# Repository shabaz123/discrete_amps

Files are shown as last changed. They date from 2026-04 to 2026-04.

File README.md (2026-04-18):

# Discrete Amps

This repository contains  discrete audio amplifier designs intended primarily for speech applications (speech bandwidth, not music).  

Each design includes:
- KiCad 10 Schematic and PCB files
- KiCad 10 SPICE Simulation Workbook
- Gerber files for fabrication  
- PDF schematic export and PCB screenshots for easy viewing without KiCad  

---

## Preamp K1

Designed by M. Kellett, this preamplifier is optimised for speech signals in HF receivers.

- **Gain:** ~28 dB  
- **Bandwidth (-3 dB):** ~150 Hz to 10 kHz (approximate)  
- **Use case:** Moderate gain front-end with relatively wide speech bandwidth  

### Schematic
K1 Schematic

### PCB Top
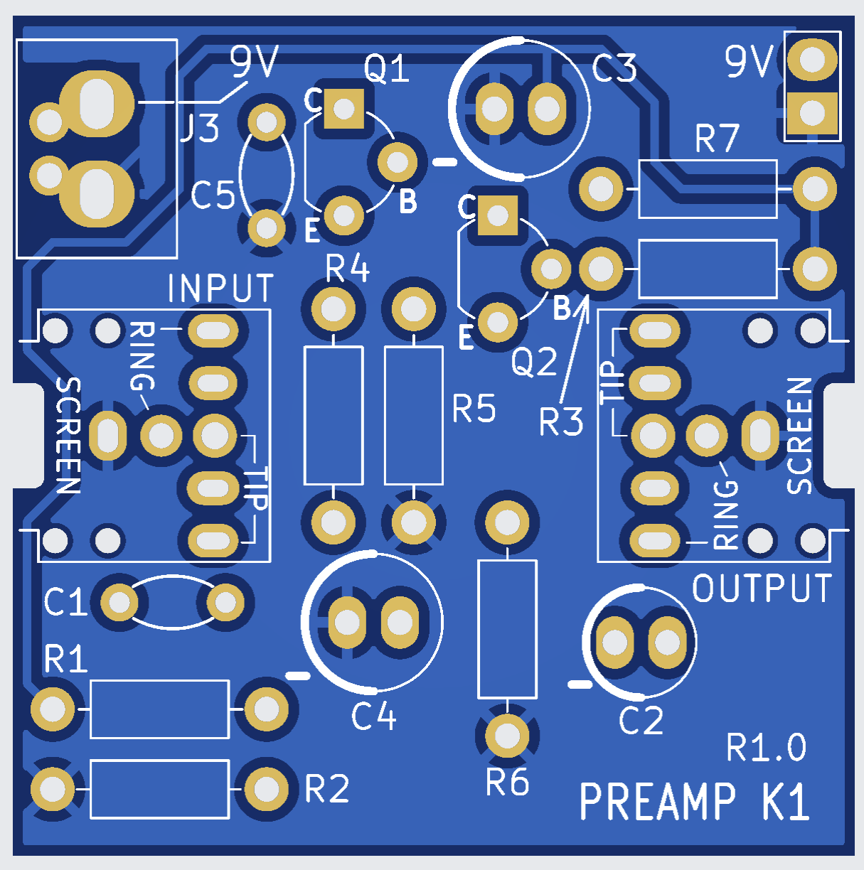
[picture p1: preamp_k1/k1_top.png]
K1 Top


### PCB Underside
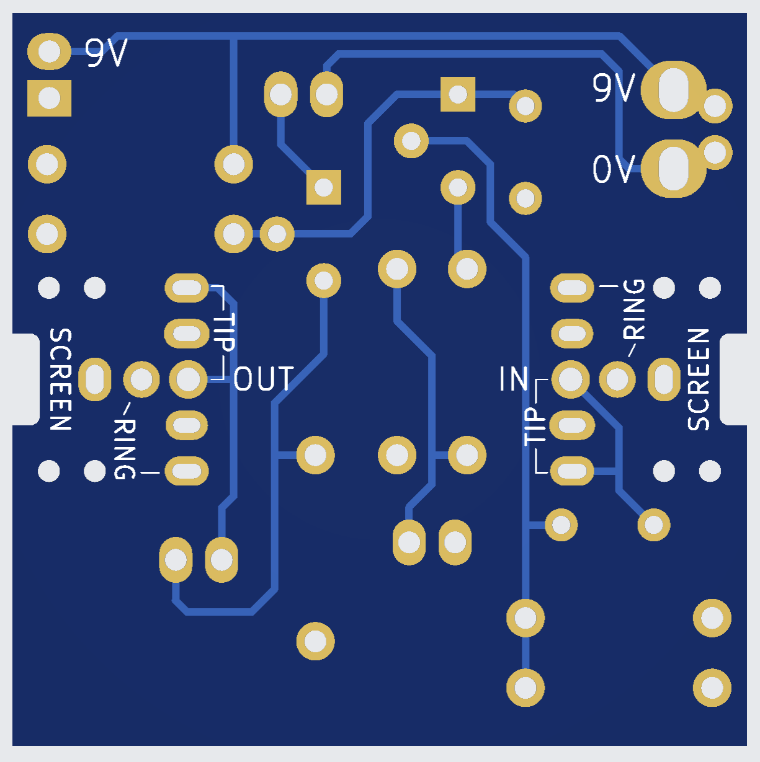
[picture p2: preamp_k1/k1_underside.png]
K1 Underside


### PCB Render
K1 Render

---

## Preamp K2

Also designed by M. Kellett, this version provides higher gain and a slightly narrower bandwidth, making it suitable where additional amplification is required.

- **Gain:** ~45 dB  
- **Bandwidth (-3 dB):** ~100 Hz to 7 kHz (approximate)  
- **Use case:** Higher gain stage for weak signal amplification  

### Schematic
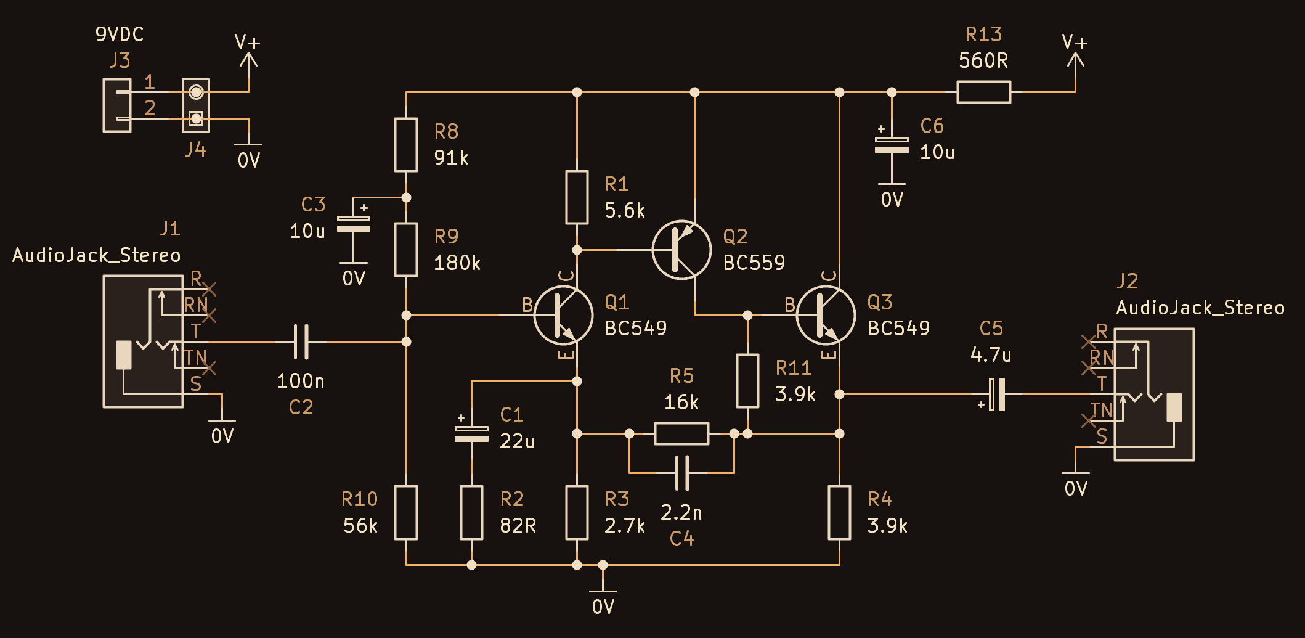
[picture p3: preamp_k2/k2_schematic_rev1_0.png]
K2 Schematic


### PCB Top
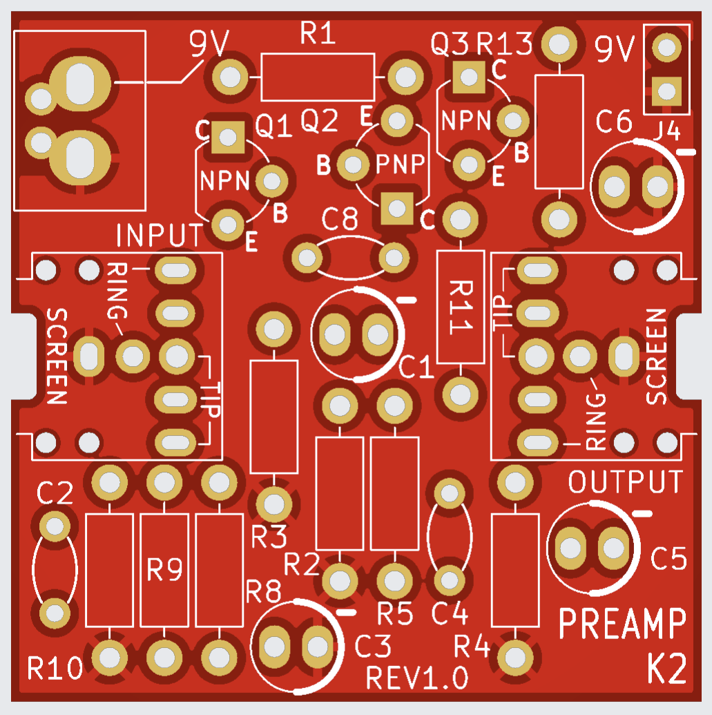
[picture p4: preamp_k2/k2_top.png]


### PCB Underside
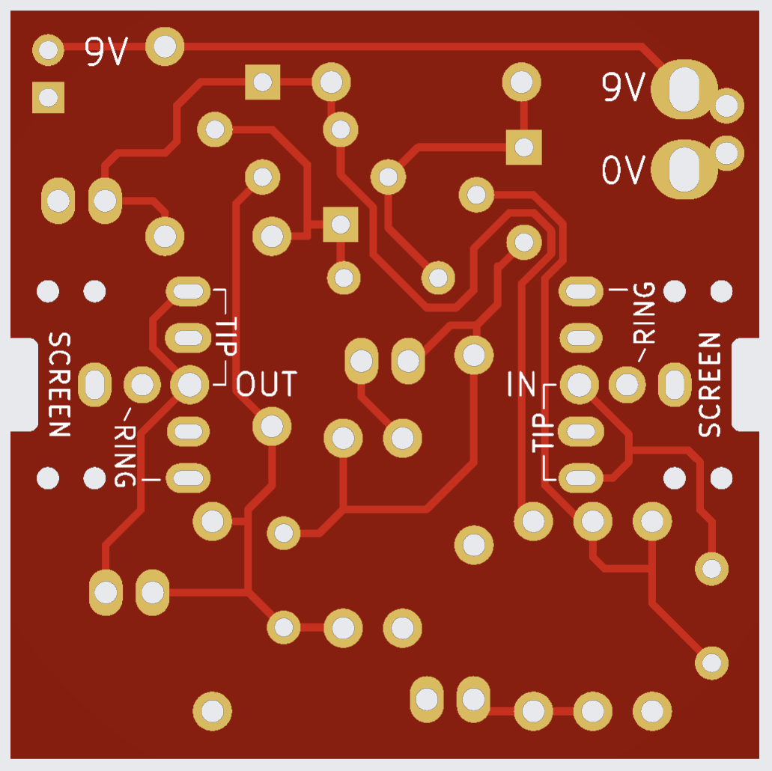
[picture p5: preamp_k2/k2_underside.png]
K2 Underside


### PCB Render
K2 Render

---

## Poweramp K1

Also designed by M. Kellett, this amplifier is a power stage, and it directly drives 8 ohm speakers, with low distortion (less than 0.5%) at 280 mW.

- **Gain:** ~27 dB  
- **Bandwidth (-3 dB):** ~50 Hz to 30 kHz (approximate)  
- **Use case:** Driving an 8-ohm speaker in a radio receiver  

### Schematic
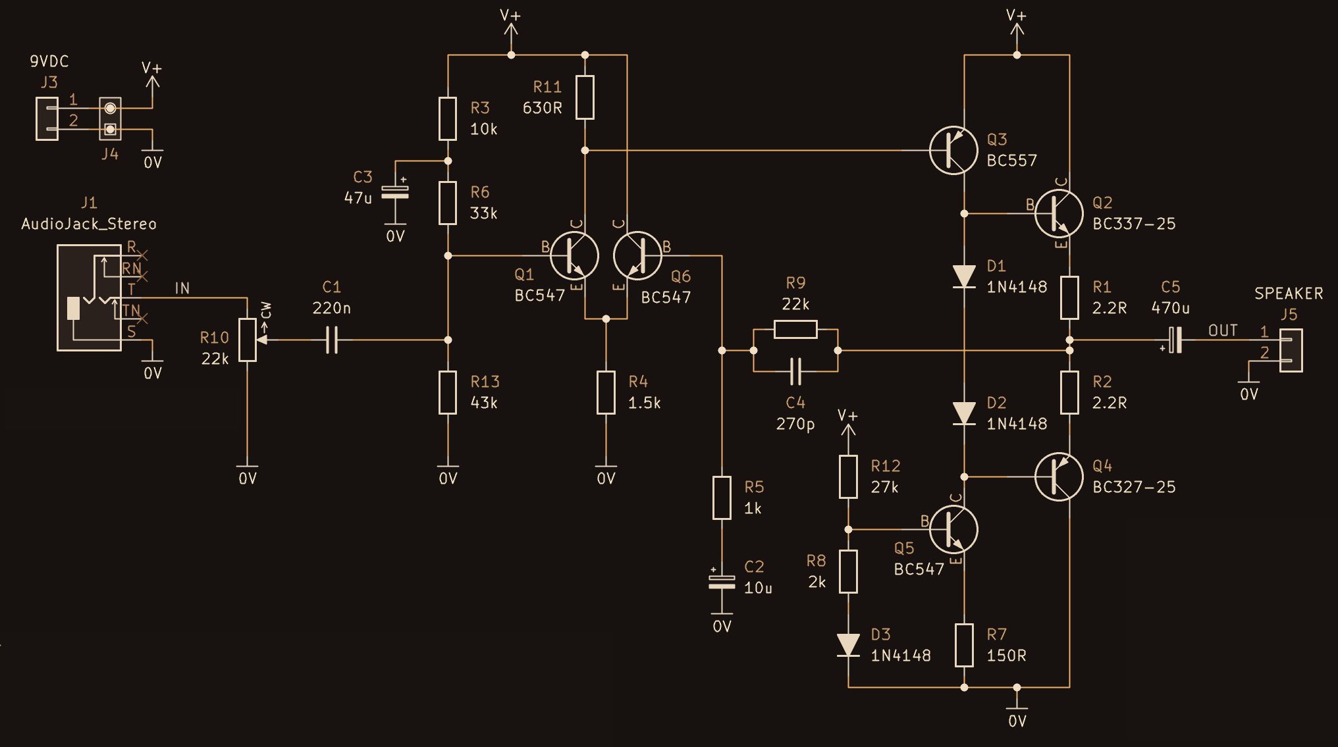
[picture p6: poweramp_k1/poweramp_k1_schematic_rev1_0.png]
K2 Schematic


### PCB Top
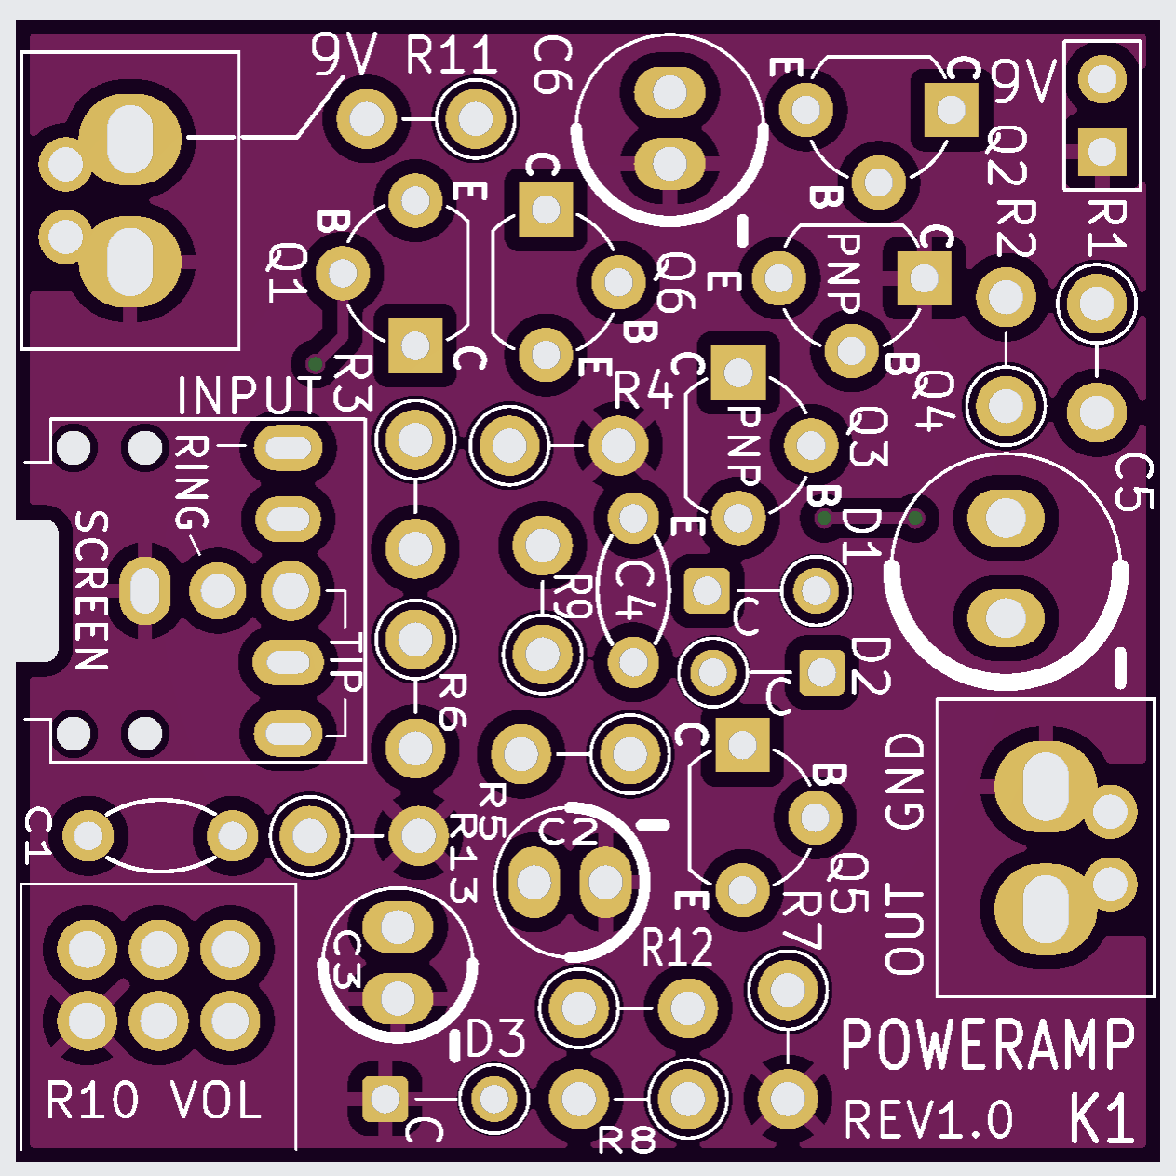
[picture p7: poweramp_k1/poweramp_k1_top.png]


### PCB Underside
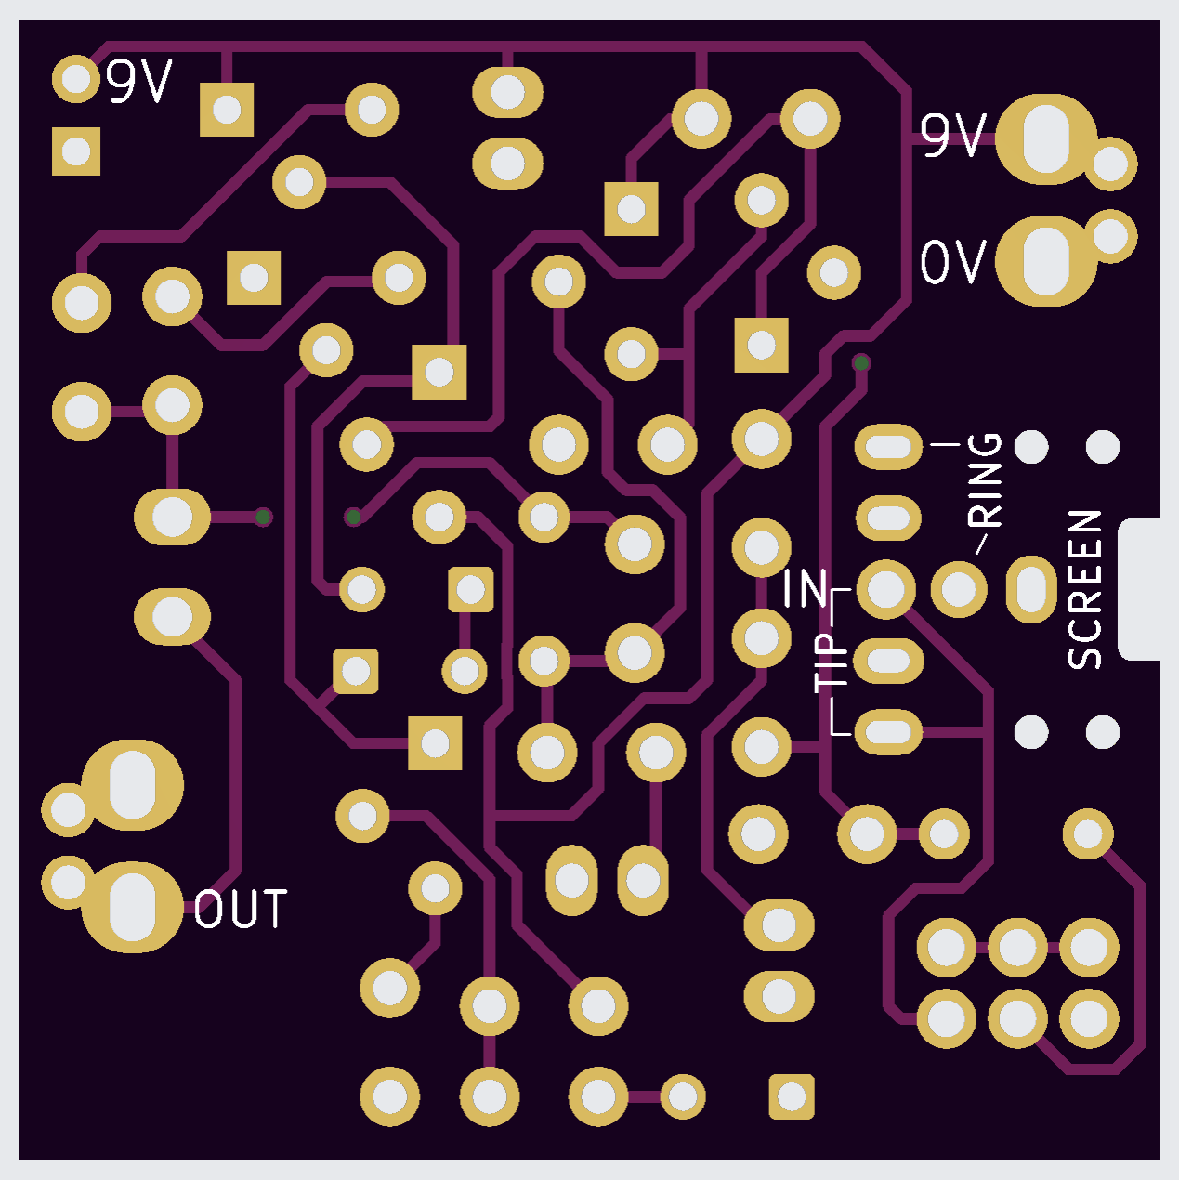
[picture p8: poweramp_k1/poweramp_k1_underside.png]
K2 Underside


### PCB Render
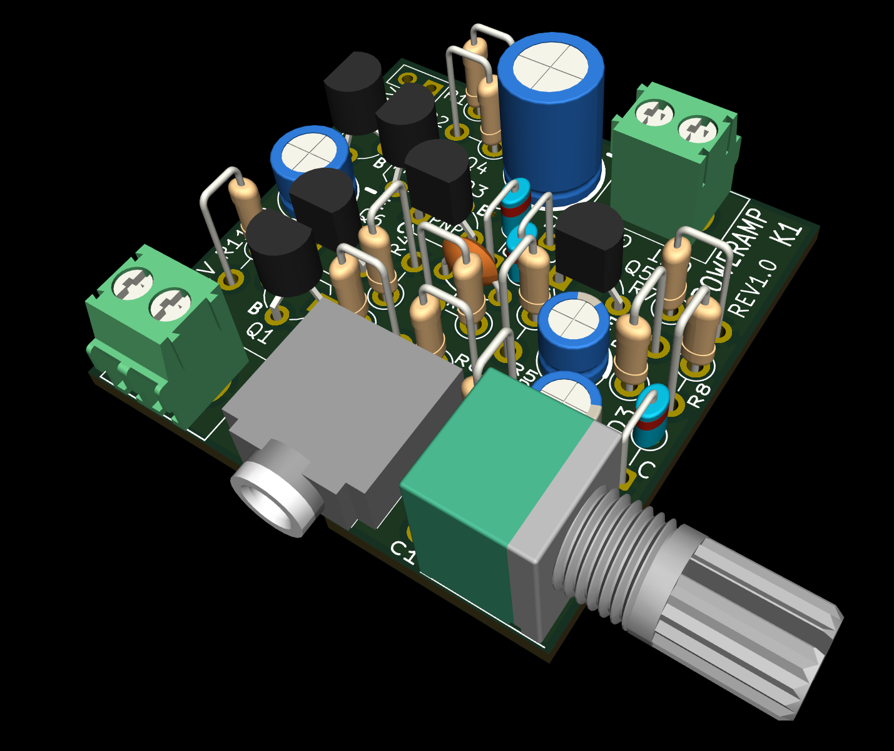
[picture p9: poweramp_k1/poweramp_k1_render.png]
K2 Render


---

## Diffamp S1

This is a difference amplifier, designed for input signals up to about 400 mV p-p. Note: this circuit has not been assembled yet, and may have instabilities. 

- **Gain:** ~10 dB  
- **Bandwidth (-3 dB):** ~30 Hz to 40 kHz (approximate)  
- **Use case:** Acting somewhat like a telephone hybrid, for a DIY intercom/field phone, to remove the local audio sound from the remotely received sound

Note: For higher gain (about 30 dB) and correspondingly lower maximum imput signals, make the following two changes:

1. Take the output from Q4 collector, rather than Q3 collector
2. Move C6 to Q4 collector instead of Q3 collector.

### Schematic
Diffamp S1 Schematic

### PCB Top
Diffamp S1 Top

### PCB Underside
Diffamp S1 Underside

### PCB Render
Diffamp S1 Render

---

## Notes

These designs are intended for experimentation and adaptation.

All components are easy to source. 

For the 9V power connection, the PCB will accomodate any 2-pin screw terminal block with 3.5 to 5.08 mm pin pitch. 

For the audio input and output, an AliExpress stereo audio jack socket can be used (only the tip and the screen is used, the ring is not connected). Alternatively, the audio connections can be made with 0.1" pin headers (they will fit in the same footprint, as there are extra holes for that). 

The potentiometer can be ALPS RK097 series (available from AliExpress), it has pins at 2.5 mm pitch, and a body width of 10 mm.

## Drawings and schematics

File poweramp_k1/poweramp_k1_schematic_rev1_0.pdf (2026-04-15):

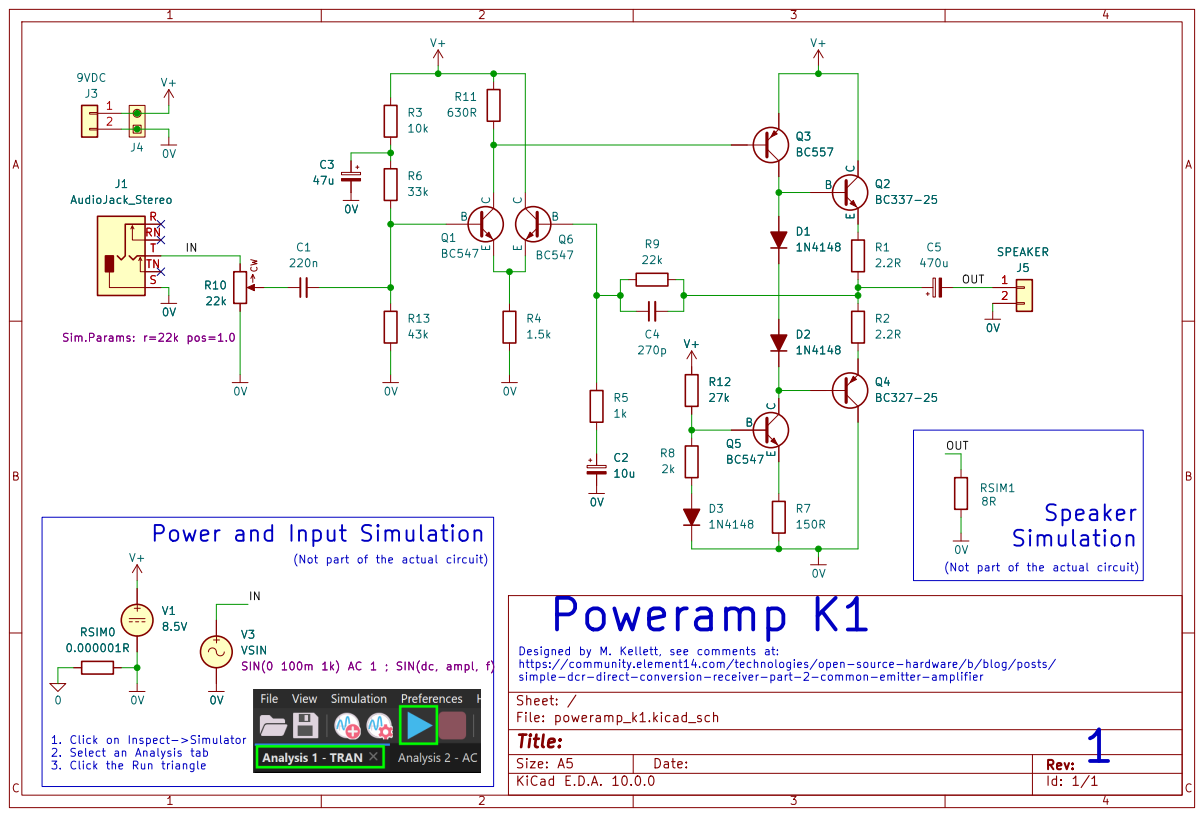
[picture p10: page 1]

Power and Input Simulation

(Not part of the actual circuit)

SIN(0 100m 1k) AC 1 ; SIN(dc, ampl, f) RSIM0

Designed by M. Kellett, see comments at: https://community.element14.com/technologies/open-source-hardware/b/blog/posts/

simple-dcr-direct-conversion-receiver-part-2-common-emitter-amplifier
Sheet: /
File: poweramp_k1.kicad_sch
Title:

1. Click on Inspect->Simulator

Size: A5 | Rev: | C Date:
KiCad E.D.A. 10.0.0 | Id: 1/1

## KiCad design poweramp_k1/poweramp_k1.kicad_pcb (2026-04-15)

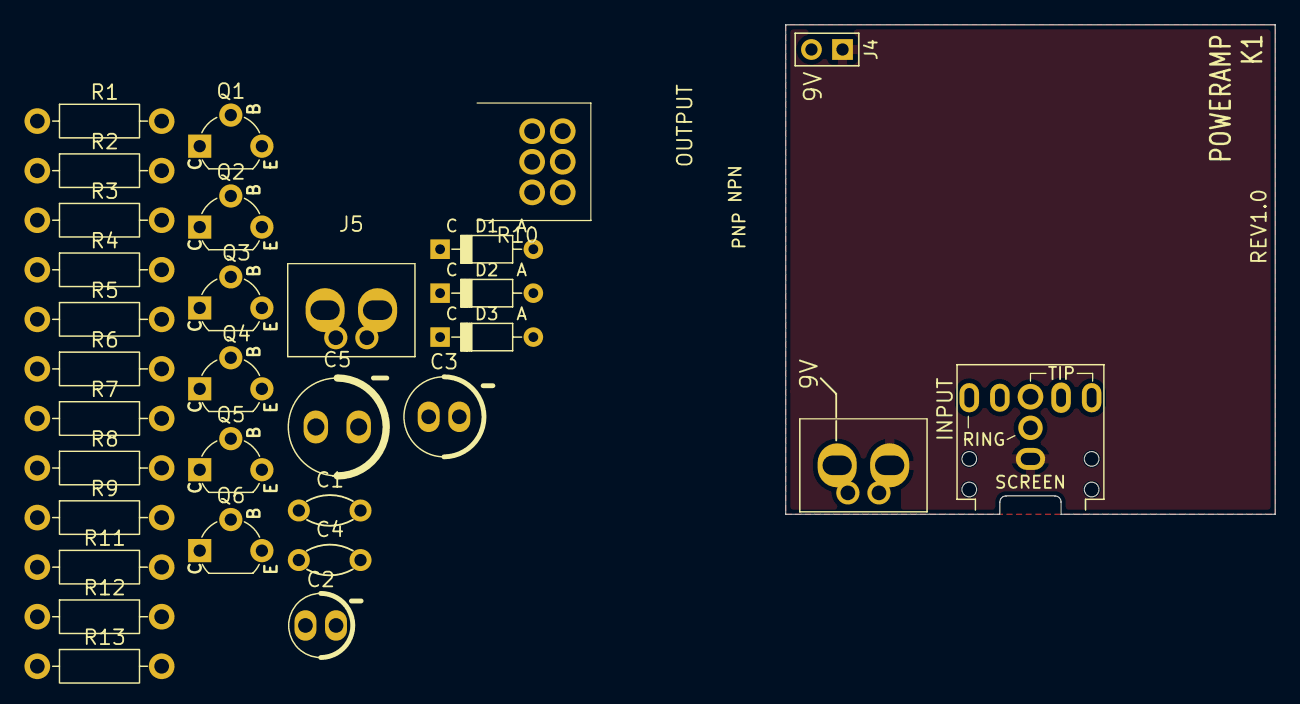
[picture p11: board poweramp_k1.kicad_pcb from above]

Board: 2 copper layers, 40.0 x 40.0 mm, 31 parts (0 on the bottom side), 20 nets, no tracks yet.

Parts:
C1: 220n; C_Disc_T3.0mm_P5.0
C2: 10u; CP_Radial_D5.0mm_P2.50mm
C3: 47u; CP_Radial_D6.3mm_P2.50mm
C4: 270p; C_Disc_T3.0mm_P5.0
C5: 470u; CP_Radial_D8mm_P3.5mm
D1, D2, D3: 1N4148; Diode-DO-35_1.75mmDia_3.4mmWidth_P7.62mm
J1: AudioJack_Stereo; Jack_3.5mm_CUI_SJ1-3525N_Horizontal
J3: 9VDC; TerminalBlock_2way-3.5-5.0mm
J4: PinHeader_1x02_P2.54mm_Vertical
J5: SPEAKER; TerminalBlock_2way-3.5-5.0mm
Q1, Q5, Q6: BC547; BJT_NPN_BC547
Q2: BC337-25; BJT_NPN_BC547
Q3: BC557; BJT_PNP_BC557
Q4: BC327-25; BJT_PNP_BC557
R1, R2: 2.2R; R_Axial_L6.3mm_D2.5mm_P10.16mm_Horiz
R3: 10k; R_Axial_L6.3mm_D2.5mm_P10.16mm_Horiz
R4: 1.5k; R_Axial_L6.3mm_D2.5mm_P10.16mm_Horiz
R5: 1k; R_Axial_L6.3mm_D2.5mm_P10.16mm_Horiz
R6: 33k; R_Axial_L6.3mm_D2.5mm_P10.16mm_Horiz
R7: 150R; R_Axial_L6.3mm_D2.5mm_P10.16mm_Horiz
R8: 2k; R_Axial_L6.3mm_D2.5mm_P10.16mm_Horiz
R9: 22k; R_Axial_L6.3mm_D2.5mm_P10.16mm_Horiz
R10: 22k; Potentiometer_RD701F
R11: 630R; R_Axial_L6.3mm_D2.5mm_P10.16mm_Horiz
R12: 27k; R_Axial_L6.3mm_D2.5mm_P10.16mm_Horiz
R13: 43k; R_Axial_L6.3mm_D2.5mm_P10.16mm_Horiz

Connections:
0V: C2.2, C3.2, D3.1 (K), J1.S, J3.2, J4.1, J5.2, Q4.1 (C), R4.2, R7.2, R10.1, R13.2
/IN: J1.T, R10.3
/OUT: C5.2, J5.1
unnamed: C1.1, R10.2
unnamed: C2.1, R5.2
unnamed: C3.1, R3.2, R6.1
unnamed: C4.2, C5.1, R1.2, R2.1, R9.2
unnamed: D1.2 (A), Q2.2 (B), Q3.1 (C)
unnamed: D1.1 (K), D2.2 (A)
unnamed: D2.1 (K), Q4.2 (B), Q5.1 (C)
unnamed: D3.2 (A), R8.2
unnamed: C1.2, Q1.2 (B), R6.2, R13.1
unnamed: Q1.1 (C), Q3.2 (B), R11.2
unnamed: Q1.3 (E), Q6.3 (E), R4.1
unnamed: Q2.3 (E), R1.1
unnamed: Q4.3 (E), R2.2
unnamed: Q5.2 (B), R8.1, R12.2
unnamed: Q5.3 (E), R7.1
unnamed: C4.1, Q6.2 (B), R5.1, R9.1
V+: J3.1, J4.2, Q2.1 (C), Q3.3 (E), Q6.1 (C), R3.1, R11.1, R12.1

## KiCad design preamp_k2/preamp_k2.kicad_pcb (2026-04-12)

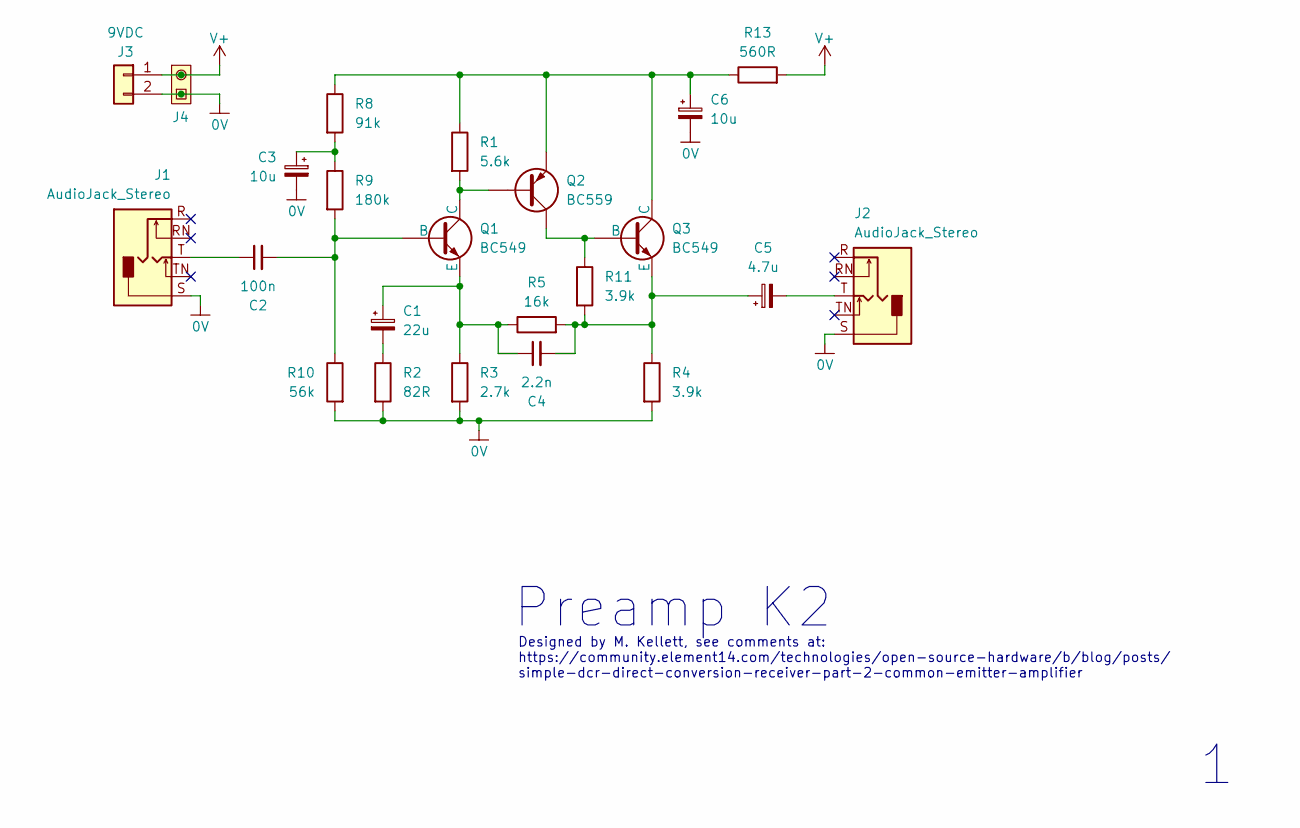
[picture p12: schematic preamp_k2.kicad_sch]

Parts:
C1: 22u; CP_Radial_D5.0mm_P2.50mm
C2: 100n; C_Disc_T3.0mm_P5.0
C3, C6: 10u; CP_Radial_D5.0mm_P2.50mm
C4: 2.2n; C_Disc_T3.0mm_P5.0
C5: 4.7u; CP_Radial_D5.0mm_P2.50mm
J1, J2: AudioJack_Stereo; Jack_3.5mm_CUI_SJ1-3525N_Horizontal
J3: 9VDC; TerminalBlock_2way-3.5-5.0mm
J4: PinHeader_1x02_P2.54mm_Vertical
Q1, Q3: BC549; BJT_NPN_BC547
Q2: BC559; BJT_PNP_BC557
R1: 5.6k; R_Axial_L6.3mm_D2.5mm_P10.16mm_Horiz
R2: 82R; R_Axial_L6.3mm_D2.5mm_P10.16mm_Horiz
R3: 2.7k; R_Axial_L6.3mm_D2.5mm_P10.16mm_Horiz
R4, R11: 3.9k; R_Axial_L6.3mm_D2.5mm_P10.16mm_Horiz
R5: 16k; R_Axial_L6.3mm_D2.5mm_P10.16mm_Horiz
R8: 91k; R_Axial_L6.3mm_D2.5mm_P10.16mm_Horiz
R9: 180k; R_Axial_L6.3mm_D2.5mm_P10.16mm_Horiz
R10: 56k; R_Axial_L6.3mm_D2.5mm_P10.16mm_Horiz
R13: 560R; R_Axial_L6.3mm_D2.5mm_P10.16mm_Horiz

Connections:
0V: C3.2, C6.2, J1.S, J2.S, J3.2, J4.1, R2.2, R3.2, R4.2, R10.2
unnamed: C1.2, R2.1
unnamed: C2.1, J1.T
unnamed: C3.1, R8.2, R9.1
unnamed: C5.2, J2.T
unnamed: C2.2, Q1.2 (B), R9.2, R10.1
unnamed: Q1.1 (C), Q2.2 (B), R1.2
unnamed: C1.1, C4.1, Q1.3 (E), R3.1, R5.1
unnamed: Q2.1 (C), Q3.2 (B), R11.1
unnamed: C6.1, Q2.3 (E), Q3.1 (C), R1.1, R8.1, R13.1
unnamed: C4.2, C5.1, Q3.3 (E), R4.1, R5.2, R11.2
V+: J3.1, J4.2, R13.2

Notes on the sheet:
Designed by M. Kellett, see comments at: https://community.element14.com/technologies/open-source-hardware/b/blog/posts/ simple-dcr-direct-conversion-receiver-part-2-common-emitter-amplifier
Preamp K2

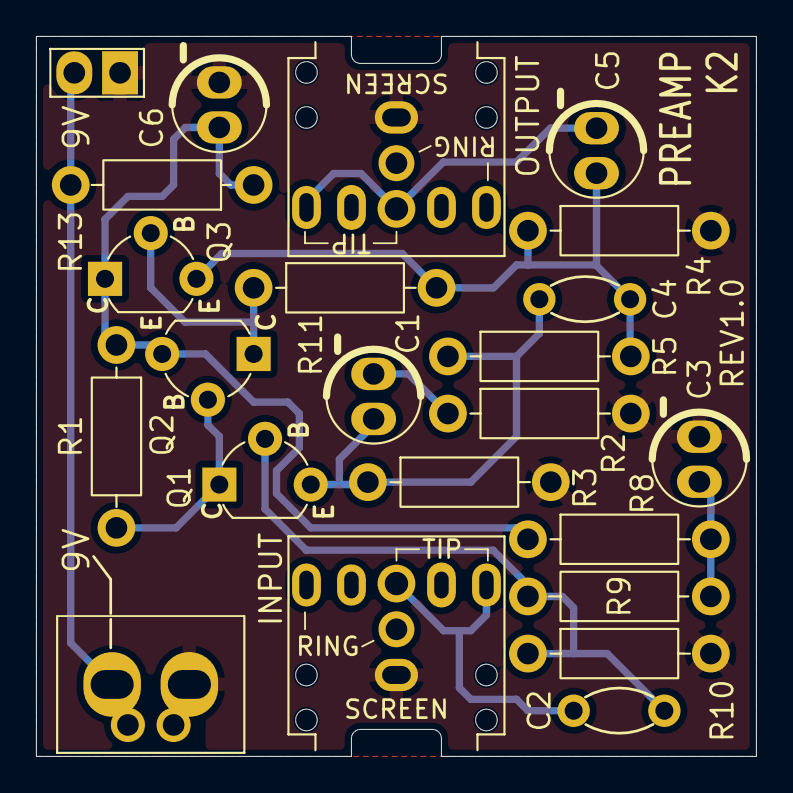
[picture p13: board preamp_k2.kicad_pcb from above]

Board: 2 copper layers, 40.0 x 40.0 mm, 23 parts (0 on the bottom side), 12 nets.

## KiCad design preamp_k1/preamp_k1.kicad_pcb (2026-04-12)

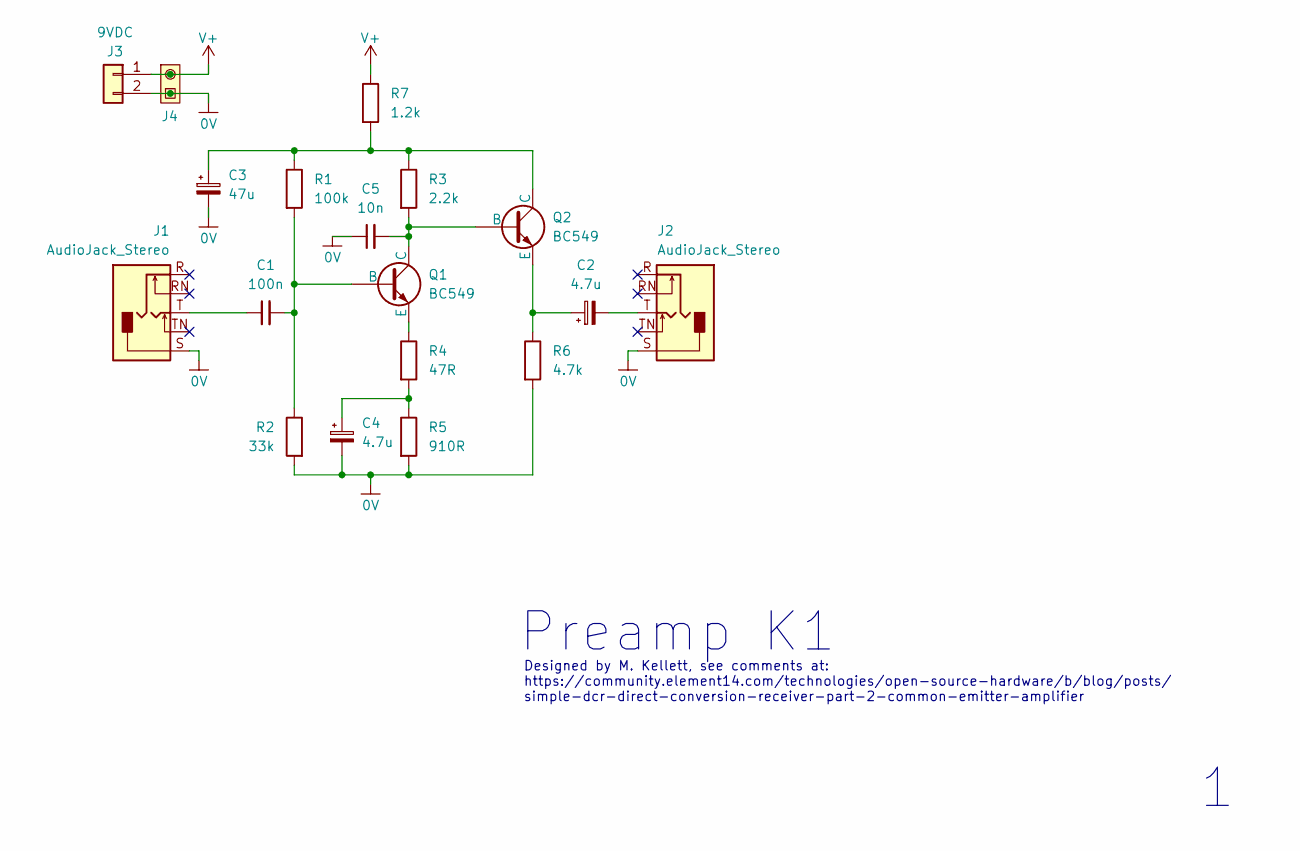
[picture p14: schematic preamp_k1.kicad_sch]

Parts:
C1: 100n; C_Disc_T3.0mm_P5.0
C2: 4.7u; CP_Radial_D5.0mm_P2.50mm
C3: 47u; CP_Radial_D6.3mm_P2.50mm
C4: 4.7u; CP_Radial_D6.3mm_P2.50mm
C5: 10n; C_Disc_T3.0mm_P5.0
J1, J2: AudioJack_Stereo; Jack_3.5mm_CUI_SJ1-3525N_Horizontal
J3: 9VDC; TerminalBlock_2way-3.5-5.0mm
J4: PinHeader_1x02_P2.54mm_Vertical
Q1, Q2: BC549; BJT_NPN_BC547
R1: 100k; R_Axial_L6.3mm_D2.5mm_P10.16mm_Horiz
R2: 33k; R_Axial_L6.3mm_D2.5mm_P10.16mm_Horiz
R3: 2.2k; R_Axial_L6.3mm_D2.5mm_P10.16mm_Horiz
R4: 47R; R_Axial_L6.3mm_D2.5mm_P10.16mm_Horiz
R5: 910R; R_Axial_L6.3mm_D2.5mm_P10.16mm_Horiz
R6: 4.7k; R_Axial_L6.3mm_D2.5mm_P10.16mm_Horiz
R7: 1.2k; R_Axial_L6.3mm_D2.5mm_P10.16mm_Horiz

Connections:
0V: C3.2, C4.2, C5.1, J1.S, J2.S, J3.2, J4.1, R2.2, R5.2, R6.2
unnamed: C1.1, J1.T
unnamed: C2.2, J2.T
unnamed: C4.1, R4.2, R5.1
unnamed: C1.2, Q1.2 (B), R1.2, R2.1
unnamed: C5.2, Q1.1 (C), Q2.2 (B), R3.2
unnamed: Q1.3 (E), R4.1
unnamed: C3.1, Q2.1 (C), R1.1, R3.1, R7.2
unnamed: C2.1, Q2.3 (E), R6.1
V+: J3.1, J4.2, R7.1

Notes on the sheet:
Designed by M. Kellett, see comments at: https://community.element14.com/technologies/open-source-hardware/b/blog/posts/ simple-dcr-direct-conversion-receiver-part-2-common-emitter-amplifier
Preamp K1

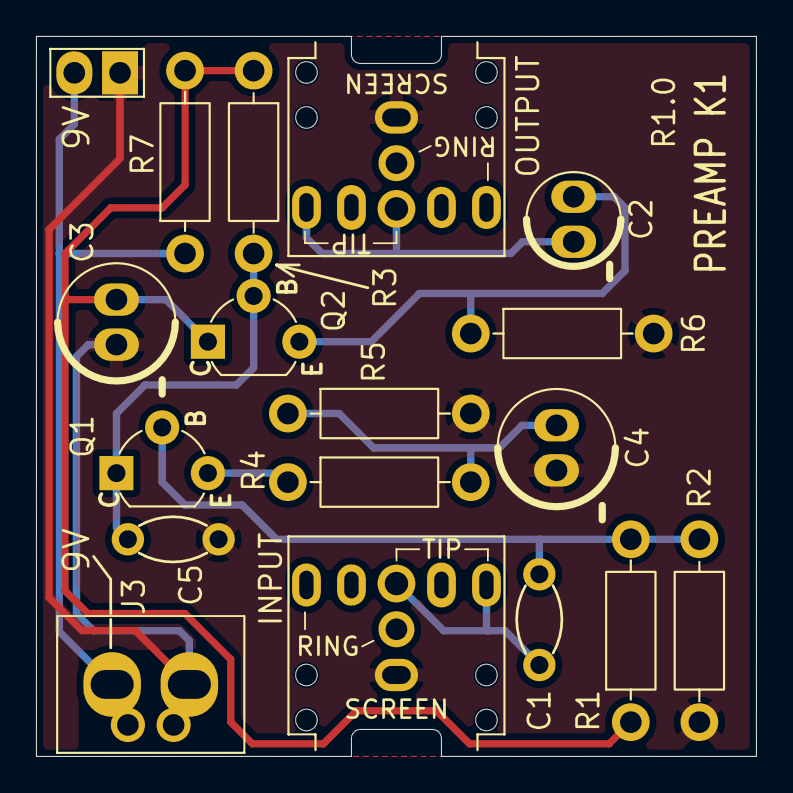
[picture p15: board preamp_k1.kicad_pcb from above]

Board: 2 copper layers, 40.0 x 40.0 mm, 18 parts (0 on the bottom side), 10 nets.

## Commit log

2026-04-12 Fix schematic image filename in README
2026-04-12 Fix typo in schematic image filename
2026-04-12 Update notes section with component sourcing details
    Added sourcing information for components and clarified PCB connections.
